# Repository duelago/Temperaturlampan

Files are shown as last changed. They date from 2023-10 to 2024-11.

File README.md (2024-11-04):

# Whamageddon lamp

A 3D-printed lamp that changes color depending on the outside temperature and, as a special feature, blinks when Last Christmas by Wham is played on the radio station. You can also monitor other songs by setting the song in the web interface. The lamp also plays a few notes from Last Christmas using an annoying buzzer when the song is detected. The API supports many european radio stations, so just check the code and you can easily figure out how to change it to your local radio station. The default setting is Mix Megapol in Sweden

You can compile the file whamageddonlamp.ino in Arduino IDE or download the .bin file (with Mix Megapol) and flash it directly with, for example, NodeMCUflasher.

The lamp consists of an addressable WS2812 LED that changes color based on the outside temperature. The data source can be any major airport in the world. Via a web interface, you input the METAR code of the airport. (The most common Swedish airports are listed on the HTML page.)

The temperature is also displayed on the OLED screen, and all weather data is presented in the web interface. The lamp checks the radio stations playlist every 30 seconds to notify you when Last Christmas is played. When detected, the lamp starts blinking. A buzzer also plays a few familiar notes, but the sound is only heard once per song play. The blinking continues until the song ends.

Here’s a video showing how it works (without the buzzer): https://youtu.be/staYxQRvpsY

I printed the case in wood filament and stained it. The star is printed in white PLA in vase mode. Other lamp designs are availabe (tulip, ball and "bambulab") The case is available in two versions, and STEP/STL files can be downloaded. Choose whether you want the version with or without mounts for M 2.5 screws. The version with screws is better, but if you don’t have any M 2.5 screws, the version without screws works if you secure the Wemos with hot glue.

The pole that the star sits on is a regular metal straw available at Amazon or a big supermarket. The components needed are:

- 3D-printed case and lid
- Wemos D1 mini v3 (the version with screw holes) https://www.aliexpress.com/item/4000420770002.html
- Wemos D1 mini OLED shield https://www.aliexpress.com/item/32804426981.html
- WS2812 LED https://www.aliexpress.com/item/1005001863273661.html
- 100-ohm resistor
- Passive buzzer https://www.aliexpress.com/item/1005006213298069.html
- Metal straw https://www.amazon.se/Alfresco-metallsugr%C3%B6r-%C3%A5teranv%C3%A4ndbara-reng%C3%B6ringsborstar-cocktail/dp/B0BKT4334T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
- Dupont wires
- Hot glue to secure the LED in the star
- Super glue
- Micro USB cable
- Heat shrink tubing (for the soldering at the LED)
- 2 M 2.5 screws (It also works without them if you print the version without screw mounts)

<h1>Wiring diagram</h1>

templampan

<h1>"Bambu" version 3D-printed lamp</h1>

co2-lampan2

<h1>Ball version</h1>

whamageddonlampan

<h1>Christmas version</h1>

temperaturlampan-stjarna

This version of the Wemos D1 fits. V3 with holes for screws.



New box for the electronics with the OLED-screen at an angle.<br>
Download the templadan-oled-angle.stl for this version


<h1>Instructions</h1>

I print my boxes and lids in PLA using a 0.6 nozzle and 0.3 mm layer height. I print the star itself in vase mode with a 0.4 nozzle and 0.2 mm layer height in white PLA. The box can definitely be printed with a 0.4 nozzle as well, but it will naturally take longer.

Other than that, just follow the wiring diagram and solder the wires in place, paying attention to which pins on the LED should be connected where. I use a bit of hot glue to secure the LED inside the star. Don't forget to use heat shrink tubing to separate the three contact points of the LED. In the Christmas version, I glue the two parts of the star together with super glue, and for the "tulip," I glue the small adapter with super glue as well.

The user connects the device with a standard micro USB cable and phone charger. The first time you connect the lamp at home, a new access point named Whamageddonlamp will appear. Connect to it via the captive portal that pops up, or through the IP address: http://192.168.4.1.

Add the lamp in WifiManager to your local wifi network, with your private wifi password. The lamp will then receive an IP address from the DHCP server at home. The user can reconnect their computer or phone to their home WiFi and access the lamp through this new IP address or via the address: http://whamageddonlamp.local. If that doesn't work, use the Fing app or a similar one on your phone to find out which IP address the lamp has been assigned.

In the web interface, you can set the airport and the song you want to monitor. These are stored in EEPROM, so they are preserved even during power outages, etc.



ezgif com-crop

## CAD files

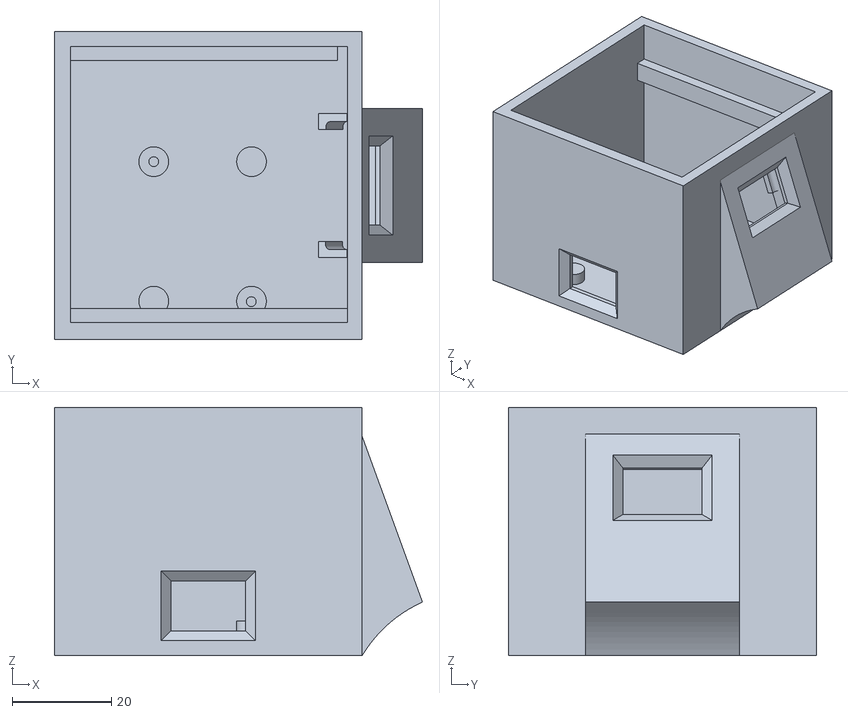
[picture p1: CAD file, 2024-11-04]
templadan-oled-angle.stl
74.1 x 62.0 x 50.0

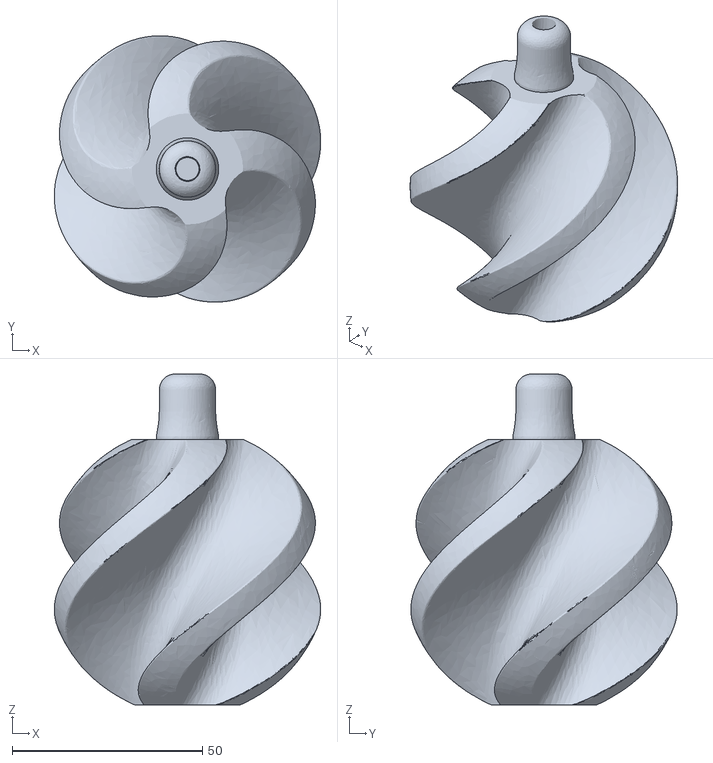
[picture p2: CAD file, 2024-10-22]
bambulab-lamp.stl
70.0 x 70.0 x 87.0

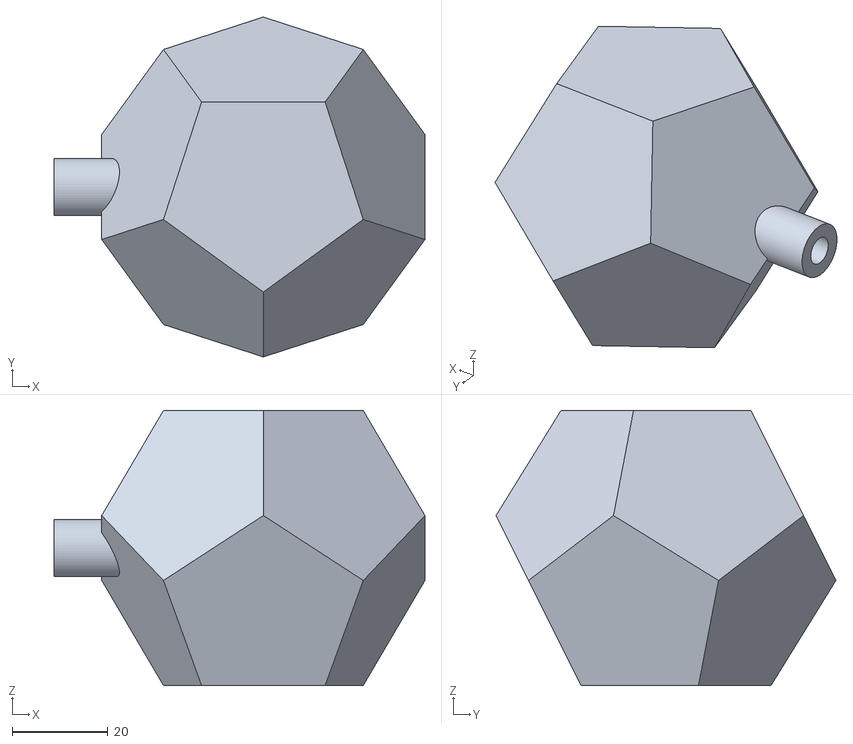
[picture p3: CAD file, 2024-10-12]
boll-lampa-v3.stl
77.6 x 71.1 x 57.5

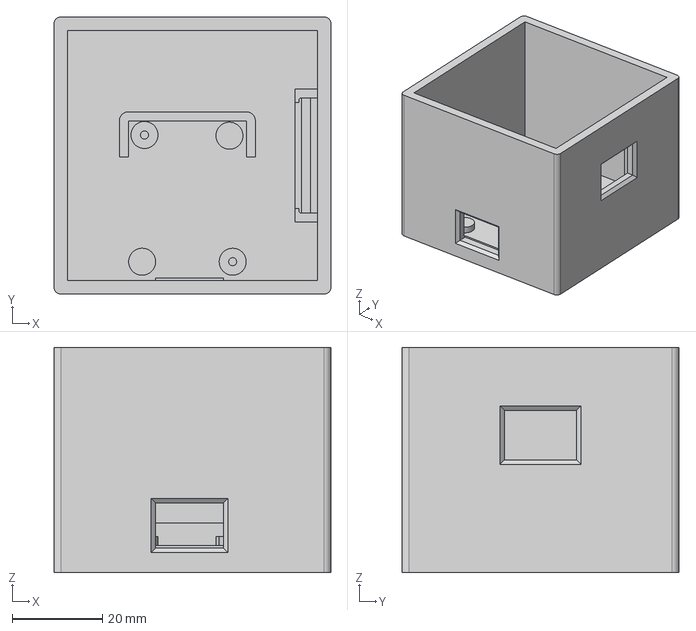
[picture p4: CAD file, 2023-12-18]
templadan-box-utan-skruv.step
61.5 x 61.5 x 50.0 mm

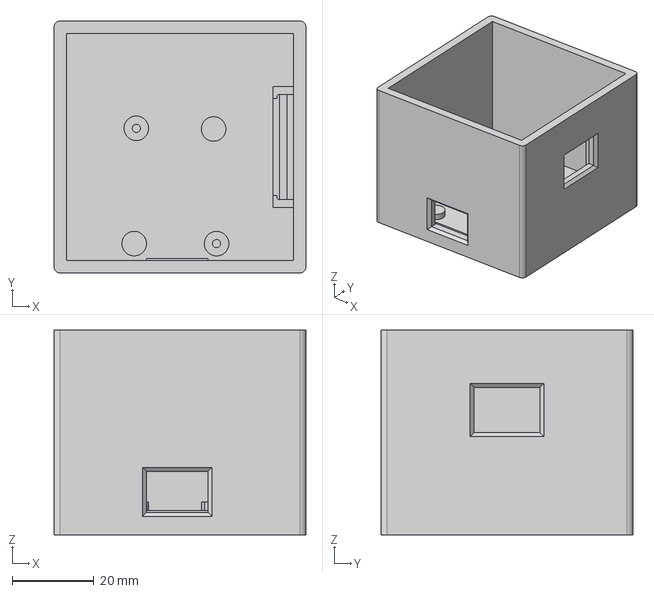
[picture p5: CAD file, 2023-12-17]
templadan-box-skruv.step
61.5 x 61.5 x 50.0 mm

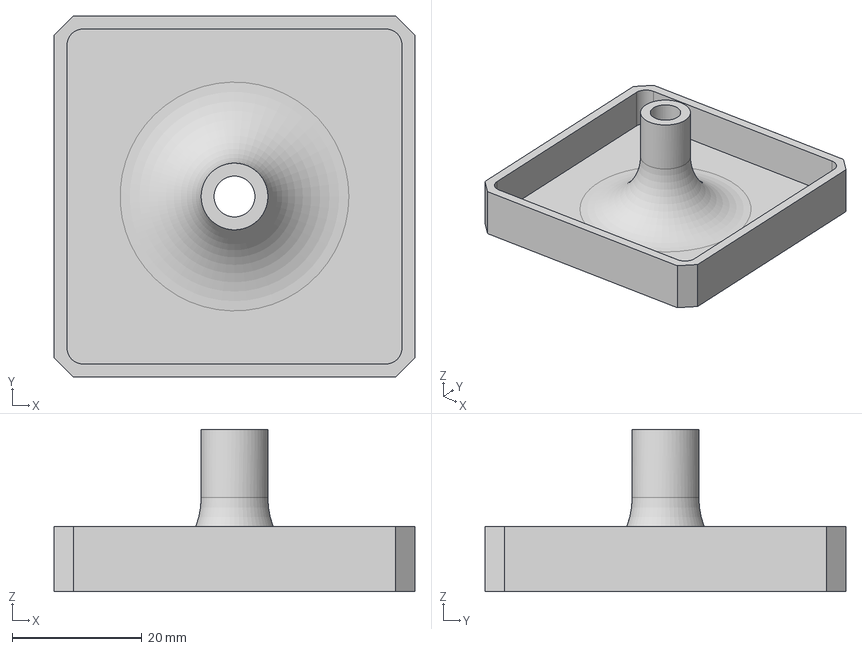
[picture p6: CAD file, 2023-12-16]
templampan-box-lock.step
55.7 x 55.7 x 25.0 mm

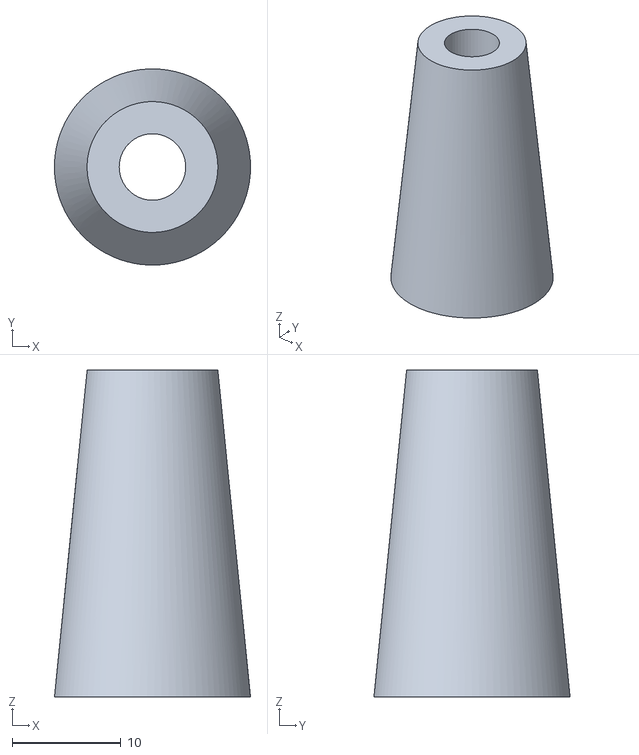
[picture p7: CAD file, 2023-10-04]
tulip-adapter.stl
18.0 x 18.0 x 30.0

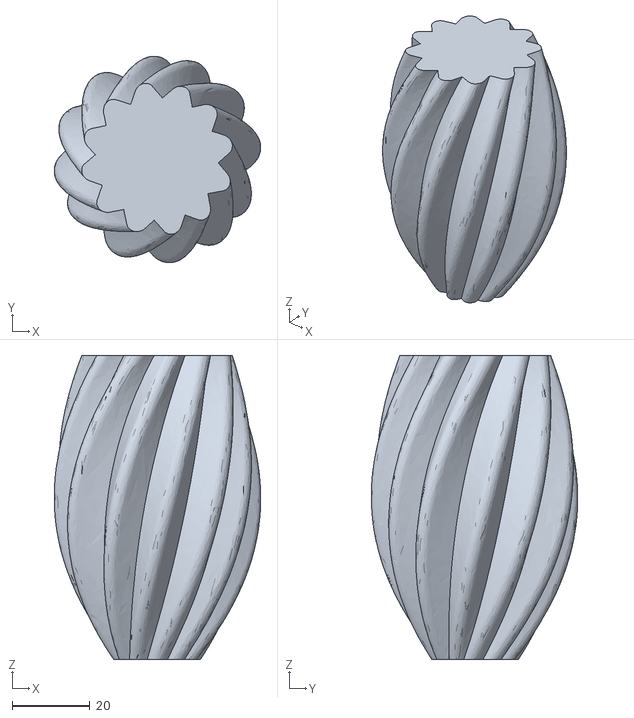
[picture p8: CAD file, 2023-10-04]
tulip.stl
53.1 x 53.1 x 78.2

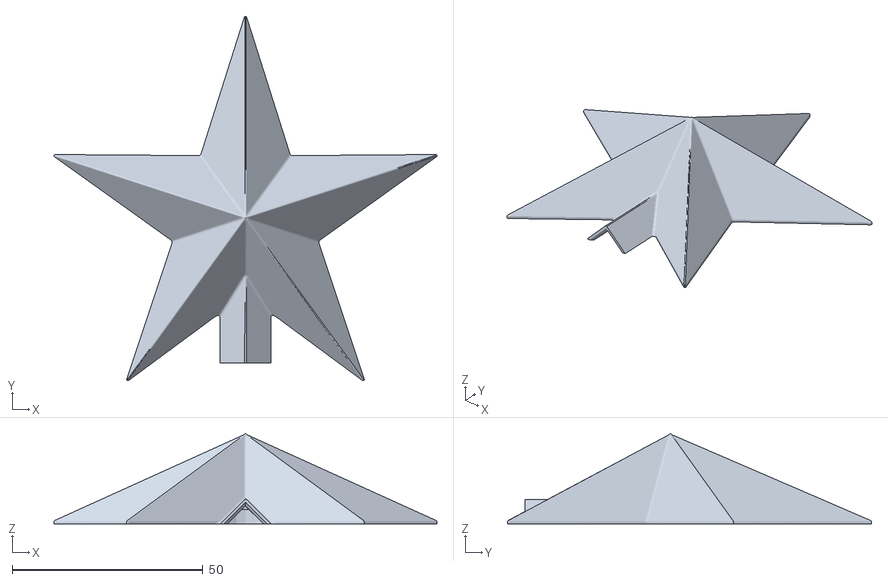
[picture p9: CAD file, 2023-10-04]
stjarna-del2.stl
100.5 x 95.6 x 23.8

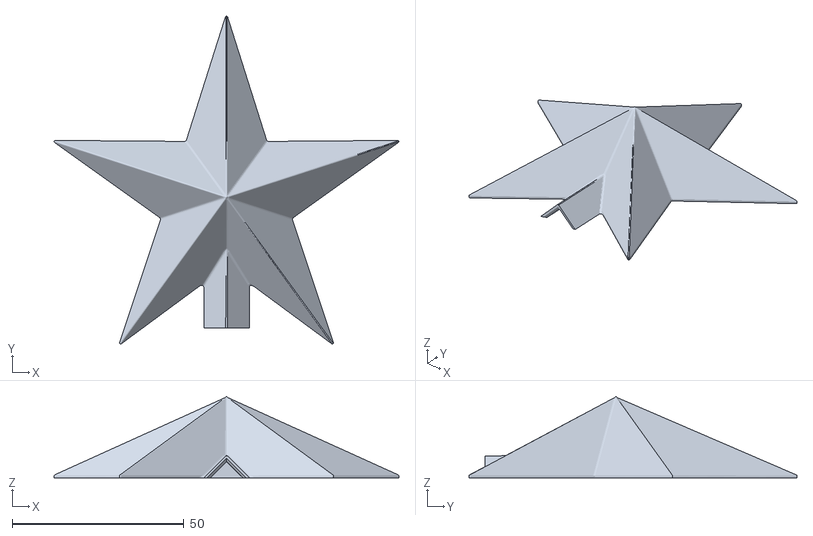
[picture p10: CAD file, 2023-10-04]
stjarna-del1.stl
100.5 x 95.6 x 23.8

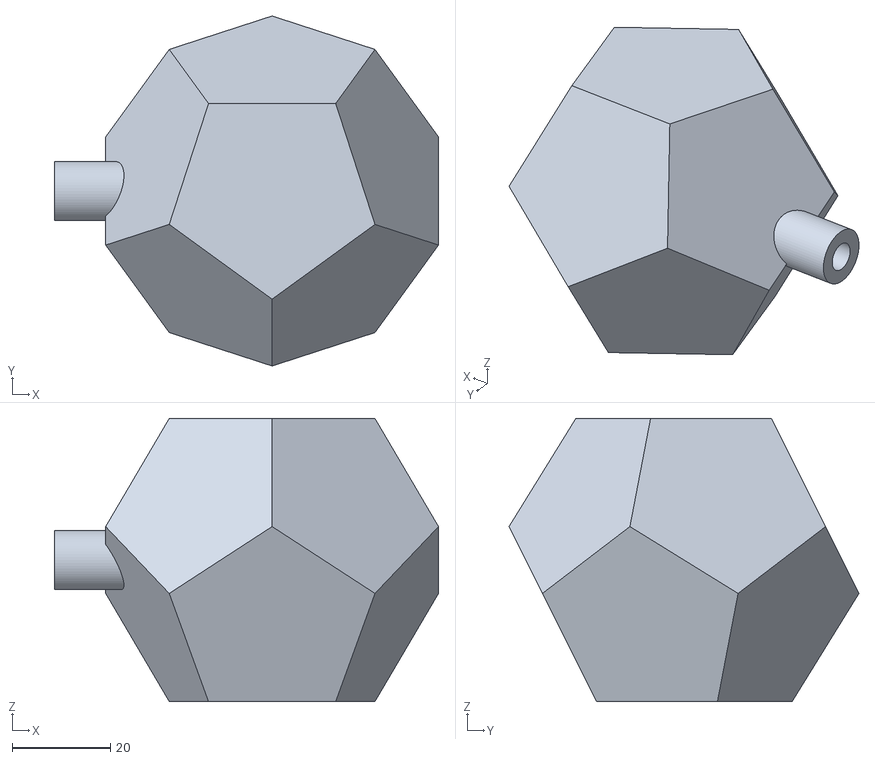
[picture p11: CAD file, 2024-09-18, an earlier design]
boll-lampa.stl
78.0 x 71.1 x 57.5

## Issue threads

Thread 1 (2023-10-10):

Problem med vissa färgkulörter

duelago, 2023-10-10:
De WS2811 LEDar jag använder är väldigt känsliga. Ibland lyser de med fel färg och ibland tänds de inte alls. Försöker finlira in kulörter som fungerar och ska prova med ett annat fabrikat av LEDs när jag får möjlighet.

Grundtipset är att använda så korta kablar som möjligt och se till att datakabeln på D4 störs så lite som möjligt av de andra kablarna. Om möjligt, använd en skärmad kabel.

Ska testa ett annat fabrikat på WS2811/2 också och se om dessa är mindre känsliga.

duelago, 2023-10-11:
Bytte till WS2812 från Elektrokit och de verkar stabilare
https://www.electrokit.com/produkt/led-rgb-5mm-adresserbar-ws2812-diffus-5-pack/

Closed 2023-10-11.

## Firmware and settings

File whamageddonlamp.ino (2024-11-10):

#include <ArduinoJson.h>
#include <ESP8266WiFi.h>
#include <ESP8266HTTPClient.h>
#include <WiFiClientSecure.h>
#include <Adafruit_NeoPixel.h>
#include <EEPROM.h>
#include <ESP8266WebServer.h>
#include <WiFiManager.h>
#include <Wire.h>
#include <Adafruit_GFX.h>
#include <Adafruit_SSD1306.h>  //special version for Wemos D1 mini
#include <ESP8266mDNS.h>
#include <DNSServer.h>
#include <ElegantOTA.h>
#define EEPROM_SIZE    100

#define OLED_RESET 0

Adafruit_SSD1306 display(OLED_RESET);

#define PIN            D4  // Define the pin for WS2811 LEDs
#define NUM_LEDS       1   // Define the number of LEDs
#define LED_BRIGHTNESS 255  // Define LED brightness (0-255)
#define EEPROM_SIZE    100   // Size of EEPROM for storing METAR station code (max 4 characters + null terminator)

Adafruit_NeoPixel strip = Adafruit_NeoPixel(NUM_LEDS, PIN, NEO_GRB + NEO_KHZ800);
ESP8266WebServer server(80);

char METARStation[5];
char storedSongTitle[EEPROM_SIZE - 5];
String METAR; // Declare METAR as a global variable
String songTitle; // Declare songTitle as a global variable
String currentSongTitle; // Declare currentSongTitle as a global variable


const unsigned long REBOOT_INTERVAL = 24 * 60 * 60 * 1000; // 24 hours in milliseconds
unsigned long previousMillis = 0;

// Add a variable to store the time the song was last played
unsigned long songPlayedTime = 0;
const unsigned long ONE_HOUR = 60 * 60 * 1000; // One hour in milliseconds

const char* apiUrl = "https://listenapi.planetradio.co.uk/api9.2/nowplaying/mme";
 //Some other stations can be found here https://listenapi.planetradio.co.uk/api9.2/stations_nowplaying

bool blinkLED = false; // Flag to control LED blinking
bool isBlinking = false; // Flag to track if LED is currently blinking
bool songPlayed = false; // Flag to track if the song has been played

unsigned long lastBlinkTime = 0;
const unsigned long blinkInterval = 500; // Blink interval in milliseconds

const unsigned long METAR_FETCH_INTERVAL = 30 * 60 * 1000; // 30 minutes in milliseconds
unsigned long lastMETARFetchTime = 0;

void song(int buzzerPin){
  
  tone(buzzerPin, 330);
  delay(602);
  noTone(buzzerPin);

  tone(buzzerPin, 330);
  delay(365);
  noTone(buzzerPin);

  tone(buzzerPin, 294);
  delay(434);
  noTone(buzzerPin);

  tone(buzzerPin, 220);
  delay(255);
  noTone(buzzerPin);

  tone(buzzerPin, 330);
  delay(203);
  noTone(buzzerPin);

  tone(buzzerPin, 330);
  delay(203);
  noTone(buzzerPin);

  tone(buzzerPin, 370);
  delay(226);
  noTone(buzzerPin);

  tone(buzzerPin, 294);
  delay(781);
  noTone(buzzerPin);

  tone(buzzerPin, 247);
  delay(185);
  noTone(buzzerPin);

  tone(buzzerPin, 247);
  delay(226);
  noTone(buzzerPin);

  tone(buzzerPin, 330);
  delay(243);
  noTone(buzzerPin);

  tone(buzzerPin, 330);
  delay(249);
  noTone(buzzerPin);

  tone(buzzerPin, 370);
  delay(336);
  noTone(buzzerPin);

  tone(buzzerPin, 294);
  delay(625);
  noTone(buzzerPin);

  tone(buzzerPin, 294);
  delay(203);
  noTone(buzzerPin);

  tone(buzzerPin, 277);
  delay(237);
  noTone(buzzerPin);

  tone(buzzerPin, 294);
  delay(220);
  noTone(buzzerPin);

  tone(buzzerPin, 277);
  delay(214);
  noTone(buzzerPin);

  tone(buzzerPin, 247);
  delay(1169);
  noTone(buzzerPin);
  }


void handleJsonObject(JsonObject obj, unsigned long currentMillis) {
    const char* trackTitle = obj["TrackTitle"];
    currentSongTitle = trackTitle;
    Serial.print("Received Track Title: ");
    Serial.println(currentSongTitle);

    if (currentSongTitle == storedSongTitle) {
        Serial.println("Stored song is playing!! Setting blinkLED flag to true.");
        blinkLED = true;
        isBlinking = true; // Set isBlinking to true when starting LED blinking

           if (!songPlayed || (currentMillis - songPlayedTime >= ONE_HOUR)) {
            songPlayed = true;
            songPlayedTime = currentMillis;
            song(14); // Play the song on pin 14
        }

   
       
    } else {
        Serial.println("Different song is playing. Keeping blinkLED flag false.");
        blinkLED = false;
        isBlinking = false; // Set isBlinking to false if not blinking
        setLEDColor(parseTemperature(METAR).toFloat()); // Update LED color based on current METAR data
    }
}


String parseTemperature(const String& metar) {
    // Find the position of "Temperature: " in the METAR string
    int tempPos = metar.indexOf("Temperature: ");
    if (tempPos != -1) {
        // Extract the substring starting from "Temperature: "
        String tempSubstring = metar.substring(tempPos);

        // Find the position of "(" and ")" to extract the Celsius temperature
        int openParenthesisPos = tempSubstring.indexOf('(');
        int closeParenthesisPos = tempSubstring.indexOf(')');

        if (openParenthesisPos != -1 && closeParenthesisPos != -1) {
            // Extract the substring between "(" and ")"
            String celsiusString = tempSubstring.substring(openParenthesisPos + 1, closeParenthesisPos);
            return celsiusString;
        }
    }

    // Return an empty string if parsing fails
    return "";
}

void setLEDColor(float tempLed) {
    uint32_t color = 0;

    if (tempLed >= 0 && tempLed <= 5) {
        color = strip.Color(255, 0, 0); // Grön
    } else if (tempLed >= -5 && tempLed < 0) {
        color = strip.Color(0, 0, 255); // Blå
    } else if (tempLed >= -50 && tempLed < -5) {
        color = strip.Color(0, 255, 255); // Lila
    } else if (tempLed >= 6 && tempLed <= 10) {
        color = strip.Color(255, 255, 0); // Gul
    } else if (tempLed >= 11 && tempLed <= 20) {
        color = strip.Color(153, 255, 0); // Orange 
    } else if (tempLed >= 21 && tempLed <= 60) {
        color = strip.Color(0, 255, 0); // Röd
    }

    for (int i = 0; i < NUM_LEDS; i++) {
        strip.setPixelColor(i, color);
    }
    strip.show();
}

void handleRoot() {
    String html = "<html><head><meta charset='UTF-8'><style>";
    html += "body { font-family: Arial, sans-serif; background-color: #f4f4f4; margin: 0; padding: 0; }";
    html += ".container { max-width: 800px; margin: 0 auto; padding: 20px; background-color: #ffffff; box-shadow: 0 0 10px rgba(0,0,0,0.1); border-radius: 10px; margin-top: 20px; }";
    html += ".input-group { margin-bottom: 20px; }";
    html += ".input-group input[type='text'] { width: 80%; padding: 8px; font-size: 16px; border: 1px solid #ccc; border-radius: 5px; }";
    html += ".input-group input[type='submit'] { width: 18%; padding: 8px; font-size: 16px; border: none; background-color: #4caf50; color: #ffffff; cursor: pointer; border-radius: 5px; }";
    html += ".metar-info { font-size: 18px; margin-top: 20px; }";
    html += ".update-link { text-decoration: none; color: #4caf50; font-weight: bold; margin-top: 20px; display: block; }";
    html += "</style></head><body>";
    html += "<div class='container'><h1>Airport code (METAR) and Song Title:</h1>";
    html += "<div class='input-group'><form method='post' action='/submit'>";
    html += "<input type='text' name='stationCode' placeholder='METAR Station Code' />";
    html += "<input type='text' name='songTitle' placeholder='Song Title' />";
    html += "<input type='submit' value='Submit' />";
    html += "</form>";
    html += "<p>";
    html += "<p>";
    html += "ESNX Arvidsjaur<br>";
    html += "ESSD Borlänge<br>";
    html += "ESNG Gällivare<br>";
    html += "ESGG Göteborg/Landvetter<br>";
    html += "ESMT Halmstad (F14)<br>";
    html += "ESUT Hemavan<br>";
    html += "ESGJ Jönköping<br>";
    html += "ESMQ Kalmar (F12)<br>";
    html += "ESOK Karlstad<br>";
    html += "ESNQ Kiruna<br>";
    html += "ESNK Kramfors/Sollefteå<br>";
    html += "ESMK Kristianstad/Everöd<br>";
    html += "ESCF Linköping/Malmen (F3)<br>";
    html += "ESTL Ljungbyhed (F5)<br>";
    html += "ESPA Luleå (F21)<br>";
    html += "ESNL Lycksele<br>";
    html += "ESMS Malmö<br>";
    html += "ESSP Norrköping/Kungsängen<br>";
    html += "ESUP Pajala<br>";
    html += "ESDF Ronneby (F17)<br>";
    html += "ESNS Skellefteå<br>";
    html += "ESGR Skövde<br>";
    html += "ESSA Stockholm/Arlanda<br>";
    html += "ESSB Stockholm/Bromma<br>";
    html += "ESKN Stockholm/Skavsta<br>";
    html += "ESOW Stockholm/Västerås<br>";
    html += "ESNN Sundsvall-Timrå<br>";
    html += "ESIB Såtenäs (F7)<br>";
    html += "ESKS Sälen<br>";
    html += "ESGT Trollhättan-Vänersborg<br>";
    html += "ESNU Umeå<br>";
    html += "ESNV Vilhelmina<br>";
    html += "ESSV Visby<br>";
    html += "ESMX Växjö/Kronoberg<br>";
    html += "ESTA Ängelholm/Barkåkra (F10)<br>";
    html += "ESOE Örebro<br>";
    html += "ESNO Örnsköldsvik/Gideå<br>";
    html += "ESNZ Östersund/Frösön (F4)";
    html += "</div>";
    html += "<div class='metar-info'>Current METAR:<br>";
    html += METAR;
    html += "<p>Song right now on Mix Megapol: ";
    html += currentSongTitle;
    html += "<p>Stored song title: ";
    html += storedSongTitle;
    html += "<p><a href='/update'>Firmware update</a></p><br>";
    html += "Version 0.7 Whamageddonlamp<br>";
    html += "</div>";
    html += "</body></html>";

    server.send(200, "text/html", html);
}


void handleSubmit() {
    String stationCode = server.arg("stationCode");
    String songTitle = server.arg("songTitle");

    // Convert the input station code to uppercase
    stationCode.toUpperCase();

    // Copy the uppercase station code to METARStation variable
    stationCode.toCharArray(METARStation, 5);

    // Copy the song title to storedSongTitle variable
    songTitle.toCharArray(storedSongTitle, EEPROM_SIZE - 5);

    // Update EEPROM with the new METAR station code and song title
    EEPROM.begin(EEPROM_SIZE);
    for (int i = 0; i < 5; ++i) {
        EEPROM.write(i, METARStation[i]);
    }
    for (int i = 0; i < EEPROM_SIZE - 5; ++i) {
        EEPROM.write(i + 5, storedSongTitle[i]);
    }
    EEPROM.end();

    // Fetch METAR data immediately after station code submission
    fetchMETARData();

    server.send(200, "text/html", "Settings updated. <a href='/'>Back</a>");
}


void fetchMETARData() {
    // Fetch METAR data using METARStation variable (e.g., "ESSA" or user-defined value)
    WiFiClientSecure client;
    client.setInsecure(); // Ignore SSL certificate verification

    HTTPClient https;
    String url = "https://tgftp.nws.noaa.gov/data/observations/metar/decoded/" + String(METARStation) + ".TXT";
    https.begin(client, url); // Use ::begin(WiFiClient, url) syntax

    int httpCode = https.GET();

    if (httpCode == HTTP_CODE_OK) {
        METAR = https.getString();
        https.end();

        // For testing purposes, print METAR data
        Serial.println("Fetching METAR data...");
        Serial.println(METAR);

        // Parse the temperature from the METAR string
        String temperature = parseTemperature(METAR);
        float tempLed = temperature.toFloat();

        // Print the temperature to the serial port
        Serial.print("The temperature is ");
        Serial.print(tempLed);
        Serial.println(" degrees Celsius.");

        display.cp437(true);
        display.clearDisplay();
        display.setTextSize(2);
        display.setTextColor(WHITE);
        display.setCursor(25, 15);
        display.print(int(tempLed));

        display.display();

        // Set LED color based on temperature
        setLEDColor(tempLed);
    } else {
        Serial.println("Failed to fetch METAR data");
        https.end();
    }
}


void setup() {
    display.begin(SSD1306_SWITCHCAPVCC, 0x3C);
    display.display();
    delay(2000);
    display.clearDisplay();
    Serial.begin(115200);
    MDNS.begin("whamageddonlamp");
    ElegantOTA.begin(&server);

    // Initialize NeoPixel strip
    strip.begin();
    strip.show();  // Initialize all pixels to 'off'

    // Use WiFiManager to set WiFi credentials if they are not already configured
    WiFiManager wifiManager;
    wifiManager.autoConnect("Whamageddonlamp");

    // Load METAR station code and song title from EEPROM
    EEPROM.begin(EEPROM_SIZE);
    for (int i = 0; i < 5; ++i) {
        METARStation[i] = EEPROM.read(i);
    }
    for (int i = 0; i < EEPROM_SIZE - 5; ++i) {
        storedSongTitle[i] = EEPROM.read(i + 5);
    }
    EEPROM.end();

    // Fetch METAR data as soon as possible after boot
    fetchMETARData();

    // Start web server
    server.on("/", HTTP_GET, handleRoot);
    server.on("/submit", HTTP_POST, handleSubmit);
    server.begin();
}


void loop() {
    unsigned long currentMillis = millis();

    // Check song title every 30 seconds
    static unsigned long lastCheckTime = 0;
    const unsigned long checkInterval = 30000;  // 30 seconds in milliseconds

    if (currentMillis - lastCheckTime >= checkInterval) {
        lastCheckTime = currentMillis;

        if (WiFi.status() == WL_CONNECTED) {
            WiFiClientSecure client;
            client.setInsecure(); // Ignore SSL certificate verification

            HTTPClient https;
            https.begin(client, apiUrl);

            int httpCode = https.GET();

            if (httpCode == HTTP_CODE_OK) {
                String payload = https.getString();
                https.end();

                StaticJsonDocument<1200> doc;
                DeserializationError error = deserializeJson(doc, payload);

                if (error) {
                    Serial.print(F("deserializeJson() failed: "));
                    Serial.println(error.f_str());
                    return;
                }

                handleJsonObject(doc.as<JsonObject>(), currentMillis);

            } else {
                Serial.printf("[HTTP] GET request failed, error: %s\n", https.errorToString(httpCode).c_str());
            }
        } else {
            Serial.println("WiFi Disconnected. Skipping song check.");
        }
    }

    // Fetch METAR data every 30 minutes
    if (currentMillis - lastMETARFetchTime >= METAR_FETCH_INTERVAL) {
        lastMETARFetchTime = currentMillis;
        fetchMETARData();
    }

    // Handle LED blinking if the flag is set
    if (blinkLED) {
        unsigned long currentBlinkTime = millis();
        if (currentBlinkTime - lastBlinkTime >= blinkInterval) {
            lastBlinkTime = currentBlinkTime;

            // Toggle LED state
            if (isBlinking) {
                strip.setPixelColor(0, strip.Color(255, 0, 0));  // Set LED to red
                strip.show();
            } else {
                strip.setPixelColor(0, strip.Color(0, 255, 0));  // Green
                strip.show();
            }

            isBlinking = !isBlinking;  // Toggle the isBlinking state
        }
    }
    
 

    server.handleClient();

    // Check if it's time to reboot the ESP8266
    if (currentMillis - previousMillis >= REBOOT_INTERVAL) {
        previousMillis = currentMillis;
        ESP.restart();
    }
}

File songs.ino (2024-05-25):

#include <FS.h>
#include <ESP8266WiFi.h>
#include <WiFiManager.h>
#include <EEPROM.h>
#include <ESP8266WebServer.h>

#define BUZZER_PIN D5
#define EEPROM_SIZE 1

ESP8266WebServer server(80);

// Function prototypes
void handleRoot();
void handleSave();
void playSong(int songIndex);
void playBangolf();
void playNeverGonnaGiveYouUp();
void playLastChristmas();

void setup() {
  Serial.begin(115200);
  
  // Initialize EEPROM
  EEPROM.begin(EEPROM_SIZE);
  
  // Initialize the file system
  SPIFFS.begin();

  // Setup WiFi using WiFiManager
  WiFiManager wifiManager;
  wifiManager.autoConnect("Wemos_D1_Mini");

  // Configure web server routes
  server.on("/", handleRoot);
  server.on("/save", handleSave);
  server.begin();

  // Read saved song from EEPROM
  int savedSong = EEPROM.read(0);
  Serial.println("Playing saved song index: " + String(savedSong));
  
  // Play the saved song
  playSong(savedSong);
}

void loop() {
  server.handleClient();
}

// Serve the main web page
void handleRoot() {
  String html = "<html><body>";
  html += "<h1>Select a Song</h1>";
  html += "<form action=\"/save\" method=\"POST\">";
  html += "<select name=\"song\">";
  html += "<option value=\"0\">Bangolf</option>";
  html += "<option value=\"1\">Never gonna give you up</option>";
  html += "<option value=\"2\">Last Christmas</option>";
  html += "</select>";
  html += "<input type=\"submit\" value=\"Save\">";
  html += "</form>";
  html += "</body></html>";

  server.send(200, "text/html", html);
}

// Handle saving the selected song
void handleSave() {
  if (server.hasArg("song")) {
    int songIndex = server.arg("song").toInt();
    EEPROM.write(0, songIndex);
    EEPROM.commit();
    Serial.println("Saved song index: " + String(songIndex));
    server.send(200, "text/plain", "Saved! Rebooting...");
    delay(1000);
    ESP.restart();
  } else {
    server.send(400, "text/plain", "Bad Request");
  }
}

// Play the selected song
void playSong(int songIndex) {
  switch (songIndex) {
    case 0:
      playBangolf();
      break;
    case 1:
      playNeverGonnaGiveYouUp();
      break;
    case 2:
      playLastChristmas();
      break;
    default:
      Serial.println("Invalid song index");
      break;
  }
}

// Define the songs
void playBangolf() {
  Serial.println("Playing Bangolf");
  tone(BUZZER_PIN, 330);
  delay(266);
  noTone(BUZZER_PIN);
  tone(BUZZER_PIN, 370);
  delay(214);
  noTone(BUZZER_PIN);
  tone(BUZZER_PIN, 415);
  delay(240);
  noTone(BUZZER_PIN);
  tone(BUZZER_PIN, 440);
  delay(230);
  noTone(BUZZER_PIN);
  tone(BUZZER_PIN, 440);
  delay(219);
  noTone(BUZZER_PIN);
  tone(BUZZER_PIN, 415);
  delay(375);
  noTone(BUZZER_PIN);
  tone(BUZZER_PIN, 370);
  delay(500);
  noTone(BUZZER_PIN);
  tone(BUZZER_PIN, 330);
  delay(375);
  noTone(BUZZER_PIN);
  tone(BUZZER_PIN, 330);
  delay(375);
  noTone(BUZZER_PIN);
  tone(BUZZER_PIN, 294);
  delay(375);
  noTone(BUZZER_PIN);
  tone(BUZZER_PIN, 277);
  delay(375);
  noTone(BUZZER_PIN);
  tone(BUZZER_PIN, 247);
  delay(375);
  noTone(BUZZER_PIN);
  tone(BUZZER_PIN, 330);
  delay(250);
  noTone(BUZZER_PIN);
  tone(BUZZER_PIN, 370);
  delay(185);
  noTone(BUZZER_PIN);
  tone(BUZZER_PIN, 415);
  delay(229);
  noTone(BUZZER_PIN);
  tone(BUZZER_PIN, 440);
  delay(230);
  noTone(BUZZER_PIN);
  tone(BUZZER_PIN, 440);
  delay(229);
  noTone(BUZZER_PIN);
  tone(BUZZER_PIN, 415);
  delay(375);
  noTone(BUZZER_PIN);
  tone(BUZZER_PIN, 370);
  delay(375);
  noTone(BUZZER_PIN);
  tone(BUZZER_PIN, 330);
  delay(375);
  noTone(BUZZER_PIN);
  tone(BUZZER_PIN, 330);
  delay(375);
  noTone(BUZZER_PIN);
  tone(BUZZER_PIN, 440);
  delay(375);
  noTone(BUZZER_PIN);
  tone(BUZZER_PIN, 415);
  delay(375);
  noTone(BUZZER_PIN);
  tone(BUZZER_PIN, 370);
  delay(201);
  noTone(BUZZER_PIN);
  tone(BUZZER_PIN, 415);
  delay(258);
  noTone(BUZZER_PIN);
  tone(BUZZER_PIN, 440);
  delay(221);
  noTone(BUZZER_PIN);
  tone(BUZZER_PIN, 440);
  delay(229);
  noTone(BUZZER_PIN);
  tone(BUZZER_PIN, 415);
  delay(250);
  noTone(BUZZER_PIN);
  tone(BUZZER_PIN, 370);
  delay(302);
  noTone(BUZZER_PIN);
  tone(BUZZER_PIN, 330);
  delay(380);
  noTone(BUZZER_PIN);
  tone(BUZZER_PIN, 277);
  delay(423);
  noTone(BUZZER_PIN);
  tone(BUZZER_PIN, 277);
  delay(250);
  noTone(BUZZER_PIN);
  tone(BUZZER_PIN, 330);
  delay(375);
  noTone(BUZZER_PIN);
  tone(BUZZER_PIN, 247);
  delay(250);
  noTone(BUZZER_PIN);
  tone(BUZZER_PIN, 247);
  delay(263);
  noTone(BUZZER_PIN);
  tone(BUZZER_PIN, 277);
  delay(517);
  noTone(BUZZER_PIN);
  tone(BUZZER_PIN, 247);
  delay(500);
  noTone(BUZZER_PIN);
  tone(BUZZER_PIN, 220);
  delay(500);
  noTone(BUZZER_PIN);
  tone(BUZZER_PIN, 220);
  delay(375);
  noTone(BUZZER_PIN);
  tone(BUZZER_PIN, 277);
  delay(375);
  noTone(BUZZER_PIN);
  tone(BUZZER_PIN, 247);
  delay(375);
  noTone(BUZZER_PIN);
  tone(BUZZER_PIN, 247);
  delay(375);
  noTone(BUZZER_PIN);
}
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

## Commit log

2023-10-04 Printa i vase mode
    [tulip.stl]
2023-10-10 Update metar.ino
    Ev har jag minnesproblem, så jag la in en restart varje 24 timme
2023-11-29 Update README.md
    Uppdaterade kopplingsschemat med bild på LED från AliExpress
2023-12-16 Ny design
    Caddade om lådan så att fästet till OLEDen printar snyggare.
    [templadan-box-v2.step]
2023-12-16 Version 2
    Lite bättre fäste för OLED-skärmen och tjockare gods
    [templadan-box-v2.step]
2023-12-16 Add files via upload
    Bättre toleranser
    [templampan-box-lock.stl]
2023-12-17 Add files via upload
    Ändrade positionen på OLEDen något
    [templadan-box-v2.step]
2023-12-17 Add files via upload
    Chamfer på OLED och USB-kontakt
    [templadan-box-v2.step]
2023-12-17 Final version
    Fixat bättre fäste för OLED-skärmen. Nu är det prima om jag får säga det själv.
    [templadan-box-v2.step]
2023-12-18 Version som inte kräver skruv
    Har du inga M 2.5 skruvar liggandes så funkar denna versionen av lådan istället. Se till att säkra Wemosen med smältlim så det går att stoppa i och ur en usb-kabel många gånger. Jag rekommenderar ver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
    [templadan-box-utan-skruv.step]
2024-04-20 MixMegapol track
    Funkar inte ännu. Fil för att hämta låttitel från Mix Megapol
2024-04-20 Update and rename lampa-megapol.ino to whamageddonlampan.ino
    Ändrade filnamn och fixade svenska tecken på HTML-sidan
    [whamageddonlampan.ino]
2024-04-22 Update whamageddonlampan.ino
    Fipplade lite med färgerna på LEDen som ändras när temperaturen ändras
2024-04-22 Update whamageddonlampan.ino
    Fipplade färgerna igen. LEDen är GRB och inte RGB så det. blev knas
2024-04-24 Update test-whamageddon.ino
    Test med buzzer
    [test-whamageddon.ino]
2024-04-25 Update test-whamageddon.ino
    Buzzer vid träff på låten
    [test-whamageddon.ino]
2024-04-25 Update test-whamageddon.ino
    Buzzer, nytt test
    [test-whamageddon.ino]
2024-04-25 Update test-whamageddon.ino
    buzzer 1 sek
    [test-whamageddon.ino]
2024-04-26 Update test-whamageddon.ino
    nytt test med buzzer
    [test-whamageddon.ino]
2024-04-26 Update test-whamageddon.ino
    mer buzztest
    [test-whamageddon.ino]
2024-04-27 Update test-whamageddon.ino
    Buzzer funkar 0.5 sek
    [test-whamageddon.ino]
2024-04-27 Update test-whamageddon.ino
    Test med buzzer avstängd 45 min
    [test-whamageddon.ino]
2024-05-16 Update and rename test-whamageddon.ino to whamageddonlampan.ino
    Buzzer implementerad
    [whamageddonlampan.ino]
2024-05-17 Update and rename whamageddonlampan.ino to whamageddonlamp.ino
    Now in English and with buzzer support
    [whamageddonlamp.ino]
2024-05-22 Update whamageddonlamp.ino
    Nu kan man bevaka valfri låt via webbinterfacet, men Last Christmas kommer trudelutta några tomer ur buzzern vid träff
    [whamageddonlamp.ino]
2024-05-22 Create rickroll.ino
    Buzzerljud för Never gonna give you up om man tröttnar på Last Christmas eller SM i Bangolf 2012 i Kalmar
    [rickroll.ino]
2024-05-22 Create testversion.ino
    Lagt till så att man kan välja buzzer ljud.
    Metar har slutat funka
    [testversion.ino]
2024-05-25 Update testversion.ino
    buzzer test
    [testversion.ino]
2024-06-25 Create new-metar-test.ino
    APIet jag använder i skarpa koden just nu kommer att läggas ner. Här är lite testkod som visar hur vi kan använda ett annat API för att fetcha temperaturen.
    En METAR kan vara ganska komplicerad så räkna inte med att parsingen funkar till 100% med denna kodsnutten ännu
2024-09-18 Add files via upload
    Behöver borras ur
    [boll-lampa.stl]
2024-10-12 Add files via upload
    I made a special version with no infill in the upper part and a lot of infill in the holder part at the bottom. This Gcode is posted in a separated file. Standard pla settings with a 0.4 nozzle on a 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
    [boll-lampa-v3.stl]
2024-10-12 Add files via upload
    Pre sliced file of the "ball" version of the lamp. Printed with 0.4 nozzle in PLA on a Prusa MK3S+
2024-10-22 Alternative lamp design
    Made a replica of the Bambulab filament design. (They showcase a model like this to promote their filaments)
    Print it with two perimeters and no infill except in the foot. (You can add segments of infill with the prusa slicer)
    [bambulab-lamp.stl]
2024-11-04 The box with the screen at an angle
    New improved version of the box.
    [templadan-oled-angle.stl]
